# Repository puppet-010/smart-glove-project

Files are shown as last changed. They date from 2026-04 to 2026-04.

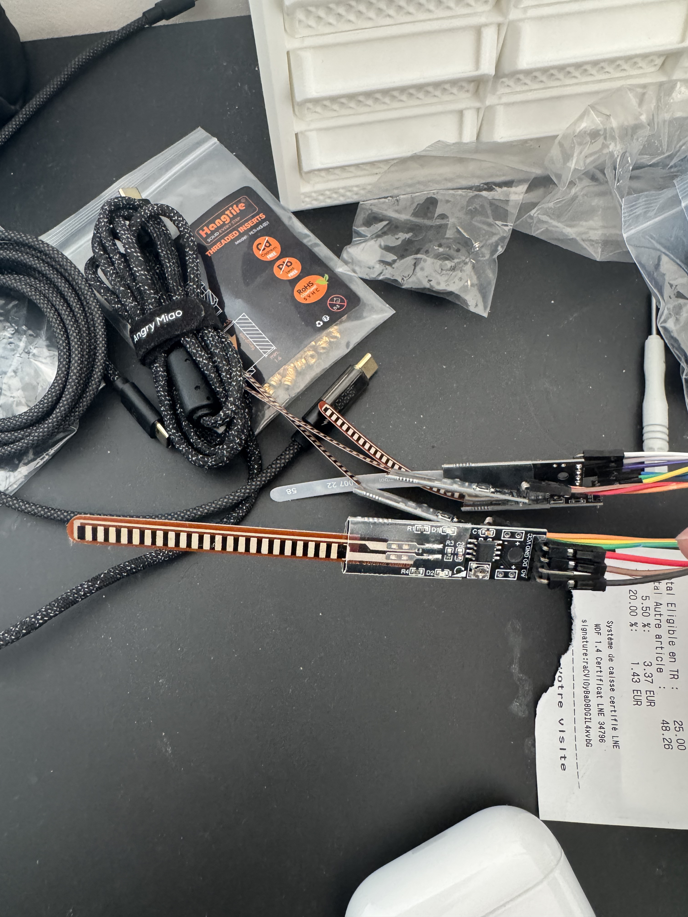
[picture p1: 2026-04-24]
media/photos/flex-sensor-overview.jpg.jpg

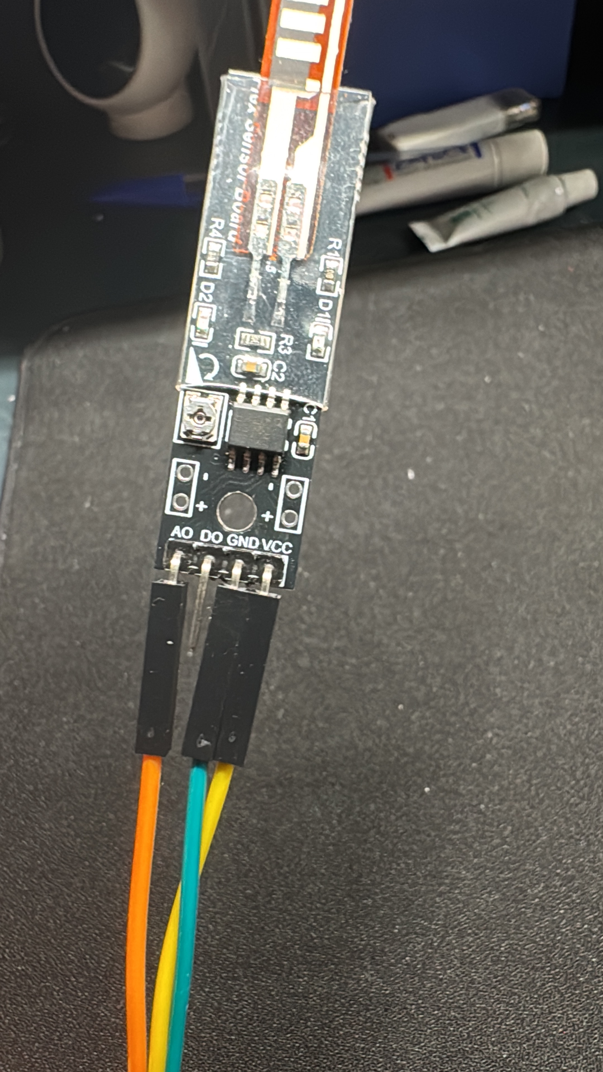
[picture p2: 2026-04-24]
media/photos/flex-sensor-module-pin-close-up.jpg

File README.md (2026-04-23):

# Smart Glove Project

A smart glove project based on five flex sensors and one IMU module for finger bending detection, hand motion sensing, and simple gesture recognition.

## Project Overview

This project was developed to build a wearable glove system capable of detecting the bending state of all five fingers and the motion of the hand. The glove combines flex sensors for finger tracking and an IMU module for hand orientation and acceleration measurement.

The system is designed as a practical prototype that can be used for gesture-based interaction and future control applications.

## Main Functions

- Detection of the bending state of five fingers
- Measurement of hand angle and acceleration using an IMU module
- Integration of sensor data into one wearable glove system
- Recognition of a first working gesture

## Current Working Result

At the current stage, the glove is fully functional.

The five flex sensors can detect the bending states of the five fingers. Four finger sensors are mounted on the back of the hand structure, while the fifth finger sensor is connected with a dedicated support solution adapted to its position.

In addition, the IMU module is used to detect the orientation and acceleration of the hand. This allows the glove not only to detect static finger positions, but also to include dynamic hand motion in the interaction logic.

A first gesture has already been implemented successfully. The working gesture is inspired by a military-style forward command: a hand sign similar to a pointing gesture, followed by two short forward motions. This result demonstrates that the glove can already be used for simple gesture recognition.

## Hardware Architecture

The system mainly includes:

- 5 flex sensors for finger bending detection
- 1 IMU module for hand motion sensing
- 1 microcontroller board for data acquisition and processing
- A glove structure with sensor supports and mechanical fixing elements
- A dedicated mounting solution for the thumb/fifth finger sensor

## Sensor Placement

The finger sensing system is based on five flex sensors.

- Four sensors are positioned on the back of the hand structure for four fingers
- The fifth finger sensor uses a dedicated connection and support method
- The IMU module is installed on the glove to capture hand angle and acceleration

This arrangement allows the system to combine finger posture detection with global hand motion sensing.

## Mechanical Design

The glove is not only an electronics project, but also a mechanical integration project.

A dedicated structure was designed to support the sensors and fix them in stable positions on the glove. CAD/mechanical design files are included in this repository to document the structure and the assembly logic.

The design was made to ensure:
- stable sensor placement
- good integration on the hand
- easy adjustment and future extension

## Repository Structure

- `firmware/` → code for flex sensor tests, IMU tests, integrated system, and gesture demo
- `hardware/` → wiring information, sensor placement, and component details
- `mechanical/` → CAD files and assembly notes
- `docs/` → calibration notes, system description, and test results
- `media/` → photos, videos, and screenshots of the project

## Demonstration Material

This repository also includes:
- project photos
- demonstration videos
- screenshots of test outputs

These materials are used to show that the glove has been physically built and tested successfully.

## Future Improvements

Possible future extensions include:

- recognition of more gestures
- improved calibration for each finger
- more advanced motion interpretation
- wireless communication
- use of the glove for robot control or other interactive applications

## Contributors

This project was developed as a team project.

Contributors will be added here.

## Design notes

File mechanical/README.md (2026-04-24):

# Mechanical Design

This folder contains the mechanical and structural design information for the smart glove project.
# Structure Notes

This document describes the main mechanical parts of the smart glove project.

## 1. Four-Finger Back-of-Hand Support

This part is the main support structure for the four fingers placed on the back of the hand.

Its role is to hold the finger sensing elements in stable positions and provide the main mechanical base for the finger control area. It helps maintain the alignment of the four finger-related components and improves the overall stability of the glove during movement.

## 2. Thumb Extension Support

This part is designed for the thumb area.

Because the thumb is positioned differently from the other four fingers, a dedicated extension support is used to connect and hold the thumb-related sensing structure. This design makes the thumb integration more practical and better adapted to the real shape and motion of the hand.

## 3. Flex Sensor Ring

This part is used to support and retain the flex sensor.

Its role is to help position the flexible sensor correctly and keep it attached to the mechanical structure. It also improves the stability of the sensing element during repeated finger motion.

## 4. Palm Support and IMU Mount

This part is used to fix the palm-side structure and hold the IMU module.

Its role is to provide a stable support area for the hand and ensure that the IMU module remains properly positioned for measuring hand orientation and acceleration. This part is important for combining finger sensing with global hand motion sensing.

## General Design Purpose

Together, these four parts form the main mechanical structure of the glove. Their purpose is to support the sensors, improve structural stability, and make the full glove system easier to assemble and use.

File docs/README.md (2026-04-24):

# Documentation

This folder contains supporting documentation for the smart glove project.

## Content

- calibration notes
- sensor interpretation logic
- gesture definition
- system architecture
- test results

## Sensor Logic and Gesture Demo

The glove uses five flex sensors to detect the bending state of the fingers and one IMU module to capture hand motion. In the current prototype, the finger signals are processed in analog mode and classified into two states: extended or bent.

A two-state logic was selected because it is more stable in the real wearable configuration. Although the flex sensors are sensitive enough for finer measurement, the actual bending variation becomes relatively small once the glove is worn, due to small gaps between the hand and the sensor support structure. In practice, a three-state interpretation was less stable, while a two-state interpretation gave more reliable results for gesture recognition.

The current demo also includes a first shooting-style gesture detection. This gesture combines a predefined finger posture with a motion condition detected by the IMU. Detailed calibration values and gesture logic are provided in the project documentation.
## Purpose

These documents explain how the glove was designed, calibrated, tested, and used for gesture recognition.

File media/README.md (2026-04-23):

# Media

This folder contains visual material related to the smart glove project.

## Content

- photos of the glove
- videos of the working system
- screenshots of outputs and tests

## Purpose

These media files are included to show that the system was physically built and successfully tested.

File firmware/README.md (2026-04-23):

# Firmware

This folder contains the code used for the smart glove project.

## Content

- flex sensor test programs
- IMU test programs
- integrated glove system code
- gesture demonstration code

## Purpose

The firmware is used to:
- read the five flex sensors
- process finger bending states
- read IMU data
- combine sensor inputs into one system
- test and recognize gestures

## Notes

The project was developed progressively, starting from sensor testing and calibration, then moving to integrated signal processing and finally to gesture implementation.

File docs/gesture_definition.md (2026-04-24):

# Gesture Definition

This document describes the first gesture recognition logic currently implemented in the smart glove project.

## 1. Current Gesture Demo

The current prototype implements a first shooting-style gesture demo.

This gesture is intended as a proof of concept showing that the glove can combine:
- finger posture detection from the flex sensors,
- motion detection from the IMU module.

## 2. General Logic

The gesture detection is based on two conditions:

1. **A predefined finger posture must be detected**
2. **A dynamic hand motion must be detected by the IMU**

Only when both conditions are satisfied is the gesture considered valid.

## 3. Finger Posture Condition

The first step is to check whether the hand matches the target posture defined in the code.

The implementation uses a specific combination of bent and extended finger states to identify the shooting-style hand position. This posture is derived from the two-state classification of the five flex sensors.

Because the project is still in a prototype phase, the exact finger-to-sensor mapping may still be refined in future integrated versions. However, the current code already provides a working posture-detection stage.

## 4. Motion Condition

Once the correct hand posture is detected, the system checks whether a dynamic motion corresponding to the gesture occurs.

The IMU is used to detect this movement through acceleration and gyroscope data. In the current implementation, the gesture is triggered when the measured motion exceeds predefined thresholds, representing a shooting-style action or recoil-like movement.

## 5. Cooldown Logic

A cooldown delay is included between two consecutive detections.

This prevents repeated triggering caused by the same movement or by rapid oscillations immediately after the gesture.

## 6. Current Role of This Gesture

The current shooting-style gesture should be understood as a first working demonstration rather than a final complete gesture library.

Its purpose is to validate the following points:
- the five-finger sensing system works in practice,
- the IMU data can be integrated into the logic,
- a combined posture + motion gesture can be recognized successfully.

## 7. Future Extensions

Future versions of the project may include:
- additional gesture definitions,
- better posture discrimination,
- more precise motion interpretation,
- improved mapping consistency between sensors and finger names,
- application of the glove to robot control or other interaction systems.

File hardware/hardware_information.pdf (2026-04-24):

## 1 Hardware Information

This document presents the main hardware elements used in the smart glove project, including the component list, wiring information, and sensor placement.

### 1.1 Component List

Component | Model / Type | Quantity | Role in the Project
Flex Sensor | 2.2-inch flex sensor | 5 | Used to detect the bending state of the five fingers.
Flex Sensor Module | LM358-based sensor mod-ule with VCC, GND, AO, DO pins | 5 | Used as the interface board for each flex sensor. The analog out-put (AO) is used in this project for more precise gesture detection.
IMU Module | MPU9250 / MPU6500 type IMU module | 1 | Used to measure hand orientation and acceleration.
Microcontroller Board | ESP32-D | 1 | Main processing unit used to read the sensors and execute the ges-ture recognition logic.
Wires | Female-to-female Dupont wires | Several | Used for electrical connections be-tween sensors, modules, and the ESP32 board.
Power Supply | Laboratory power supply | 1 | Temporary external power source used during the experimental stage.

Table 1: Main hardware components of the smart glove project

### 1.2 Wiring Information

The smart glove uses five flex sensors, each associated with one finger. Each flex sensor is connected to an interface module providing four pins: VCC, GND, AO, and DO. In this project, the analog output pin (AO) is used, since it allows more detailed measurement of the finger bending state and provides better support for gesture recognition than the digital output.
The five flex sensor analog outputs are connected to the ESP32-D board through the following GPIO pins:
- GPIO32
- GPIO33
- GPIO34

1

- GPIO35
- GPIO39

The IMU module is connected to the ESP32 through the I²C interface. The IMU communication lines are connected to the ESP32 I²C pins (SDA and SCL). In the current prototype, these lines are connected to GPIO21 and GPIO22.

### 1.3 Sensor Placement

The glove uses one flex sensor for each finger, giving a total of five finger sensors.

- Four flex sensors are placed on the back-of-hand finger structure.
- The fifth flex sensor is used for the thumb area through a dedicated support solution.
- The IMU module is placed on the upper back side of the hand, close to the ESP32 board.

This arrangement allows the system to detect both local finger bending states and global hand motion.

### 1.4 Remarks

At the current stage, the system is powered by a laboratory power supply because no dedicated embedded power module has yet been integrated into the glove. This choice is suitable for testing and validation during the prototype phase.
The use of analog outputs for the flex sensors is an important design choice in this project, because it makes the interpretation of finger positions more flexible and improves the detection of gesture variations.

2

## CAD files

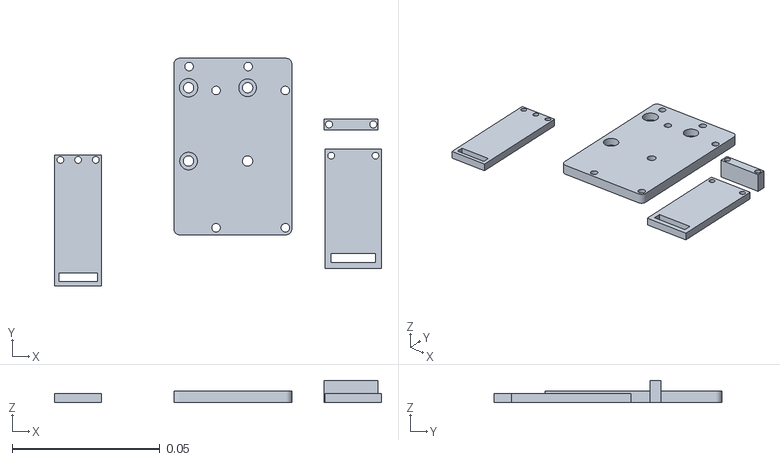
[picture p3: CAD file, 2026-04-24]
mechanical/Palm Support and IMU Mount.stl
0.111 x 0.0771 x 0.0075

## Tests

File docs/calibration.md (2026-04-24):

# Calibration and Sensing Logic

This document describes the reading method, filtering logic, and calibration values used for the smart glove project.

## 1. Reading Method

The flex sensors are read in analog mode rather than digital mode.

Each flex sensor is connected through a sensor module providing four pins: VCC, GND, AO, and DO. In this project, the analog output (AO) is used because it preserves more detailed information about finger bending and makes gesture interpretation more flexible.

For each sensor, the signal is not read only once. Instead, the system performs multiple consecutive analog readings and computes an average value. This helps reduce small fluctuations and provides a more stable measurement.

## 2. Filtering Method

A simple averaging filter is used in the current implementation.

For each flex sensor:
- 10 readings are taken
- a delay of 2 ms is inserted between samples
- the final value is the average of the 10 readings

This method is simple but effective for improving the stability of the raw sensor signal.

## 3. Why a Two-State Classification Was Chosen

At the beginning, a more detailed multi-state interpretation was considered.

In theory, flex sensors are sensitive enough to support finer distinctions of finger positions. However, in the real wearable configuration, the sensors do not remain in perfect contact with the hand all the time. Even after assembly, small gaps still exist between the hand and the sensor support structure.

As a result:
- the effective bending variation becomes relatively small,
- the measured values change quickly,
- the intermediate range is not always stable enough for consistent classification.

In practice, a three-state interpretation was less robust for the current prototype. For this reason, the final implementation uses a two-state classification:
- **Extended**
- **Bent**

This simplified logic gives more stable results for gesture recognition.

## 4. Finger Reference Values

The following table summarizes the current reference ranges measured for each finger.

| Finger | GPIO | Flat Value (approx.) | Bent Value (approx.) | Threshold |
|---|---:|---:|---:|---:|
| Index | 34 | 850–1000 | 50–100 | 200 |
| Middle | 35 | 1000–1150 | 60–120 | 250 |
| Ring | 32 | 1200–1400 | 150–250 | 300 |
| Thumb | 39 | 1650–1750 | 1150–1300 | 1350 |
| Pinky | 33 | 1500–1600 | 950–1200 | 1200 |

## 5. Threshold Interpretation

The current thresholds are finger-specific.

This means that each finger is calibrated independently instead of using one common threshold for all sensors. This choice is necessary because the sensors do not produce the same numerical range on every finger. In particular, the thumb and pinky operate in a significantly higher range than the other fingers.

The thresholds are currently used to convert the filtered analog readings into two discrete states:
- one state corresponding to the extended finger position,
- one state corresponding to the bent finger position.

## 6. Current Limitations

The current values provide a working solution for the prototype, but they are still dependent on:
- the mechanical fit of the glove,
- the way the glove is worn,
- the exact position of each sensor,
- the user’s hand shape and bending amplitude.

Because of these factors, the calibration may vary slightly between users or between mechanical revisions.

## 7. Possible Future Improvements

Possible improvements for future versions include:
- more precise per-user calibration,
- improved mechanical contact between the glove and the hand,
- better support for intermediate finger positions,
- adaptive thresholds,
- more advanced filtering and signal interpretation.

At the current stage, the chosen calibration logic is sufficient for stable operation of the first gesture recognition prototype.

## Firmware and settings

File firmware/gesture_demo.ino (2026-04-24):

#include <Wire.h>
 
// ===== FLEX SENSORS =====

const int NB_SENSORS = 5;

// Ordre corrigé : Thumb, Index, Middle, Ring, Pinky

const int SENSOR_PINS[NB_SENSORS] = {34, 35, 32, 39, 33};

const char* fingerName[NB_SENSORS] = {
  "Index", "Middle", "Ring", "Thumb", "Pinky"
};


int threshold[NB_SENSORS] = {
  200,   // Index  GPIO34
  250,   // Middle GPIO35
  300,   // Ring   GPIO32
  1350,  // Thumb  GPIO39
  1200   // Pinky  GPIO33
};

 
// ===== MPU6500 =====

const int MPU6500_ADDR = 0x68;

const int ACCEL_XOUT_H = 0x3B;

const int GYRO_XOUT_H = 0x43;

const int PWR_MGMT_1 = 0x6B;
 
// Seuils de détection du mouvement de recul (tir)

const float RECOIL_ACCEL_THRESHOLD = 1.5;  // g (accélération vers l'arrière)

const float GYRO_THRESHOLD = 100.0;         // degrés/s (rotation du poignet)

const int RECOIL_COOLDOWN = 500;           // ms entre deux détections
 
unsigned long lastShotTime = 0;

bool shotDetected = false;
 
// ===== FONCTIONS FLEX =====

int readStable(int pin) {

  long sum = 0;

  for (int i = 0; i < 10; i++) {

    sum += analogRead(pin);

    delay(2);

  }

  return sum / 10;

}
 
int getPosition2States(int raw, int th) {

  if (raw > th) return 1;

  else return 3;

}
 
// ===== FONCTIONS MPU6500 =====

void writeMPU(byte reg, byte data) {

  Wire.beginTransmission(MPU6500_ADDR);

  Wire.write(reg);

  Wire.write(data);

  Wire.endTransmission();

}
 
int16_t readMPU16(byte reg) {

  Wire.beginTransmission(MPU6500_ADDR);

  Wire.write(reg);

  Wire.endTransmission(false);

  Wire.requestFrom(MPU6500_ADDR, 2);

  int16_t value = Wire.read() << 8;

  value |= Wire.read();

  return value;

}
 
void initMPU6500() {

  Wire.begin();

  delay(100);

  // Réveiller le MPU6500

  writeMPU(PWR_MGMT_1, 0x00);

  delay(100);

  // Configuration de l'accéléromètre : ±4g

  writeMPU(0x1C, 0x08);

  // Configuration du gyroscope : ±500°/s

  writeMPU(0x1B, 0x08);

  Serial.println("MPU6500 initialisé");

}
 
void readMPU6500(float &accelX, float &gyroY, float &gyroZ) {

  // Lire accéléromètre X (axe vertical quand main en position pistolet)

  int16_t ax = readMPU16(ACCEL_XOUT_H);

  accelX = ax / 8192.0; // ±4g scale

  // Lire gyroscope Y et Z (rotation du poignet)

  int16_t gy = readMPU16(GYRO_XOUT_H + 2);

  int16_t gz = readMPU16(GYRO_XOUT_H + 4);

  gyroY = gy / 65.5; // ±500°/s scale

  gyroZ = gz / 65.5;

}
 
bool detectShootingGesture(int pos[]) {

  // Vérifier la position des doigts : Index et Majeur tendus, autres pliés

  bool thumbBent = (pos[0] == 3);        // Pouce plié

  bool indexExtended = (pos[1] == 1);    // Index tendu

  bool middleExtended = (pos[2] == 1);   // Majeur tendu

  bool ringBent = (pos[3] == 3);         // Annulaire plié

  bool pinkyBent = (pos[4] == 3);        // Auriculaire plié

  return indexExtended && middleExtended && thumbBent && ringBent && pinkyBent;

}
 
bool detectRecoil(float accelX, float gyroY, float gyroZ) {

  // Détection du recul : accélération négative sur X (vers l'arrière)

  // et rotation du poignet (gyro)

  bool recoilAccel = (accelX < -RECOIL_ACCEL_THRESHOLD);

  bool wristRotation = (abs(gyroY) > GYRO_THRESHOLD || abs(gyroZ) > GYRO_THRESHOLD);

  return recoilAccel || wristRotation;

}
 
void setup() {

  Serial.begin(115200);

  delay(1000);

  Serial.println("=== DÉTECTEUR DE TIR AU PISTOLET ===");

  Serial.println("Position : Index et Majeur tendus, autres doigts pliés");

  Serial.println("MPU6500 : Axe X vertical");

  Serial.println("====================================");

  Serial.println("Pins corrigés:");

  Serial.println("  Thumb  -> GPIO34");

  Serial.println("  Index  -> GPIO35");

  Serial.println("  Middle -> GPIO32");

  Serial.println("  Ring   -> GPIO39");

  Serial.println("  Pinky  -> GPIO33");

  Serial.println("====================================");

  initMPU6500();

}
 
void loop() {

  // ===== LECTURE FLEX SENSORS =====

  int raw[NB_SENSORS];

  int pos[NB_SENSORS];

  for (int i = 0; i < NB_SENSORS; i++) {

    raw[i] = readStable(SENSOR_PINS[i]);

    pos[i] = getPosition2States(raw[i], threshold[i]);

  }

  // ===== LECTURE MPU6500 =====

  float accelX, gyroY, gyroZ;

  readMPU6500(accelX, gyroY, gyroZ);

  // ===== DÉTECTION DU GESTE =====

  bool isGunPosition = detectShootingGesture(pos);

  // Détection du tir (mouvement de recul)

  if (isGunPosition && !shotDetected && (millis() - lastShotTime > RECOIL_COOLDOWN)) {

    if (detectRecoil(accelX, gyroY, gyroZ)) {

      Serial.println(">>> TIR DÉTECTÉ! <<<");

      shotDetected = true;

      lastShotTime = millis();

    }

  } else if (!detectRecoil(accelX, gyroY, gyroZ)) {

    shotDetected = false;

  }

  // ===== AFFICHAGE =====

  Serial.println("------");

  // Affichage des doigts

  for (int i = 0; i < NB_SENSORS; i++) {

    Serial.print(fingerName[i]);

    Serial.print(" (GPIO");

    Serial.print(SENSOR_PINS[i]);

    Serial.print("): ");

    Serial.print(pos[i] == 1 ? "TENDU" : "PLIÉ");

    Serial.print(" (");

    Serial.print(raw[i]);

    Serial.println(")");

  }

  // Affichage MPU6500

  Serial.print("Accel X: ");

  Serial.print(accelX, 2);

  Serial.print(" g | Gyro Y: ");

  Serial.print(gyroY, 1);

  Serial.print(" | Gyro Z: ");

  Serial.println(gyroZ, 1);

  // Statut

  Serial.print("Position pistolet: ");

  Serial.println(isGunPosition ? "OUI ✓" : "NON");

  delay(50); // Lecture plus rapide pour détecter le mouvement

}
 

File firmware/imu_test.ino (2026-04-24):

#include <Wire.h>

#include <math.h>

 

#define MPU_ADDR 0x68   // AD0接地一般就是0x68，若不通可试0x69

 

// ESP32 I2C引脚

#define SDA_PIN 21

#define SCL_PIN 22

 

// MPU寄存器

#define REG_WHO_AM_I    0x75

#define REG_PWR_MGMT_1  0x6B

#define REG_ACCEL_XOUT_H 0x3B

#define REG_GYRO_CONFIG  0x1B

#define REG_ACCEL_CONFIG 0x1C

 

int16_t rawAx, rawAy, rawAz;

int16_t rawGx, rawGy, rawGz;

 

float ax, ay, az;   // 单位 g

float gx, gy, gz;   // 单位 deg/s

 

float pitch, roll;

 

void writeRegister(uint8_t reg, uint8_t value) {

  Wire.beginTransmission(MPU_ADDR);

  Wire.write(reg);

  Wire.write(value);

  Wire.endTransmission();

}

 

uint8_t readRegister(uint8_t reg) {

  Wire.beginTransmission(MPU_ADDR);

  Wire.write(reg);

  Wire.endTransmission(false);

 

  Wire.requestFrom(MPU_ADDR, (uint8_t)1);

  if (Wire.available()) {

    return Wire.read();

  }

  return 0xFF;

}

 

void readMPU() {

  Wire.beginTransmission(MPU_ADDR);

  Wire.write(REG_ACCEL_XOUT_H);

  Wire.endTransmission(false);

 

  Wire.requestFrom(MPU_ADDR, (uint8_t)14);

 

  if (Wire.available() >= 14) {

    rawAx = (Wire.read() << 8) | Wire.read();

    rawAy = (Wire.read() << 8) | Wire.read();

    rawAz = (Wire.read() << 8) | Wire.read();

 

    Wire.read(); Wire.read();   // 温度先跳过

 

    rawGx = (Wire.read() << 8) | Wire.read();

    rawGy = (Wire.read() << 8) | Wire.read();

    rawGz = (Wire.read() << 8) | Wire.read();

  }

 

  // 默认配置下：

  // 加速度 ±2g -> 16384 LSB/g

  // 陀螺仪 ±250 dps -> 131 LSB/(deg/s)

  ax = rawAx / 16384.0;

  ay = rawAy / 16384.0;

  az = rawAz / 16384.0;

 

  gx = rawGx / 131.0;

  gy = rawGy / 131.0;

  gz = rawGz / 131.0;

}

 

void computeAngles() {

  // 仅用加速度计估算倾角，适合静态或慢速动作

  roll  = atan2(ay, az) * 180.0 / PI;

  pitch = atan2(-ax, sqrt(ay * ay + az * az)) * 180.0 / PI;

}

 

void setup() {

  Serial.begin(115200);

  delay(1000);

 

  Wire.begin(SDA_PIN, SCL_PIN);

  Wire.setClock(400000);

 

  Serial.println("Start MPU6500 / MPU9250 test...");

 

  // 唤醒MPU

  writeRegister(REG_PWR_MGMT_1, 0x00);

  delay(100);

 

  // 加速度量程设为 ±2g

  writeRegister(REG_ACCEL_CONFIG, 0x00);

 

  // 陀螺仪量程设为 ±250 deg/s

  writeRegister(REG_GYRO_CONFIG, 0x00);

 

  delay(100);

 

  uint8_t whoami = readRegister(REG_WHO_AM_I);

  Serial.print("WHO_AM_I = 0x");

  Serial.println(whoami, HEX);

 

  if (whoami == 0x70) {

    Serial.println("Detected MPU6500");

  } else if (whoami == 0x71) {

    Serial.println("Detected MPU9250");

  } else if (whoami == 0x73) {

    Serial.println("Possible MPU9255 / similar");

  } else {

    Serial.println("Unknown device, check wiring/address!");

  }

}

 

void loop() {

  readMPU();

  computeAngles();

 

  Serial.println("------------");

  Serial.print("Accel (g): ");

  Serial.print("ax=");

  Serial.print(ax, 3);

  Serial.print("  ay=");

  Serial.print(ay, 3);

  Serial.print("  az=");

  Serial.println(az, 3);

 

  Serial.print("Gyro (deg/s): ");

  Serial.print("gx=");

  Serial.print(gx, 2);

  Serial.print("  gy=");

  Serial.print(gy, 2);

  Serial.print("  gz=");

  Serial.println(gz, 2);

 

  Serial.print("Angle (deg): ");

  Serial.print("pitch=");

  Serial.print(pitch, 2);

  Serial.print("  roll=");

  Serial.println(roll, 2);

 

  delay(200);

}

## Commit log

2026-04-23 Create README.md
    Hardware information, wiring, and component details.
2026-04-23 Create README.md
    Mechanical design files and assembly notes.
2026-04-23 Create README.md
    Project documentation, calibration notes, and system architecture.
2026-04-23 Create README.md
    Photos of the glove, sensors, and final assembly.
